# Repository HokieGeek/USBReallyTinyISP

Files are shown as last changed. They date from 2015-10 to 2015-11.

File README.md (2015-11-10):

# USBReallyTinyISP
SMT version of [Adafruit's USBtinyISP](https://learn.adafruit.com/usbtinyisp) with a form factor inspired by [SparkFun's AVR Adapter](http://www.sparkfun.com/products/retired/8508).

 This work is licensed as  *Creative Common 4.0 Attribution-ShareAlike*
## Schematic
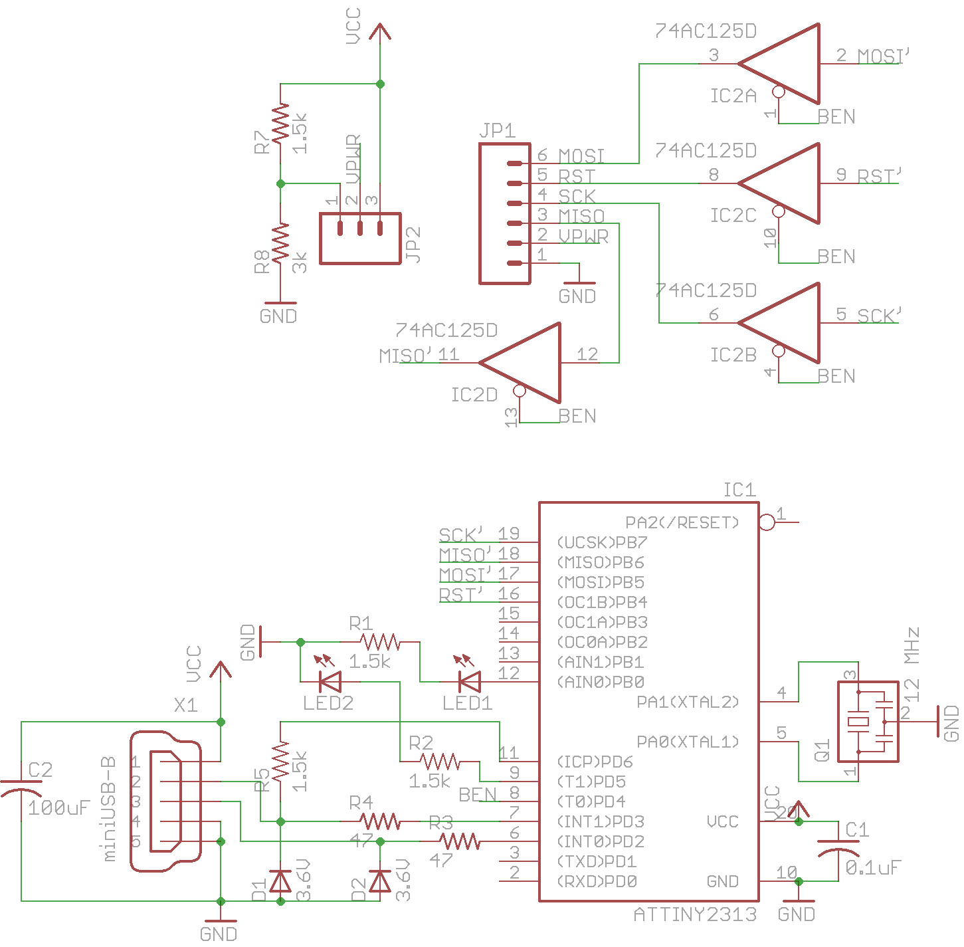
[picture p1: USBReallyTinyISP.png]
Latest USBReallyTinyISP Schematic


## Board
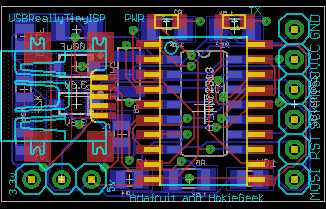
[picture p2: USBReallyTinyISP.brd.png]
Latest USBReallyTinyISP Board


## Datasheets
* [ATtiny2313](http://www.atmel.com/images/doc2543.pdf)
* [74AHC125](http://www.ti.com/lit/ds/symlink/sn74ahc125.pdf)

[Mouser project](https://www.mouser.com/ProjectManager/ProjectDetail.aspx?ProjectGUID=dc6b4dca-204f-45ba-9732-e10048a6dd5b)

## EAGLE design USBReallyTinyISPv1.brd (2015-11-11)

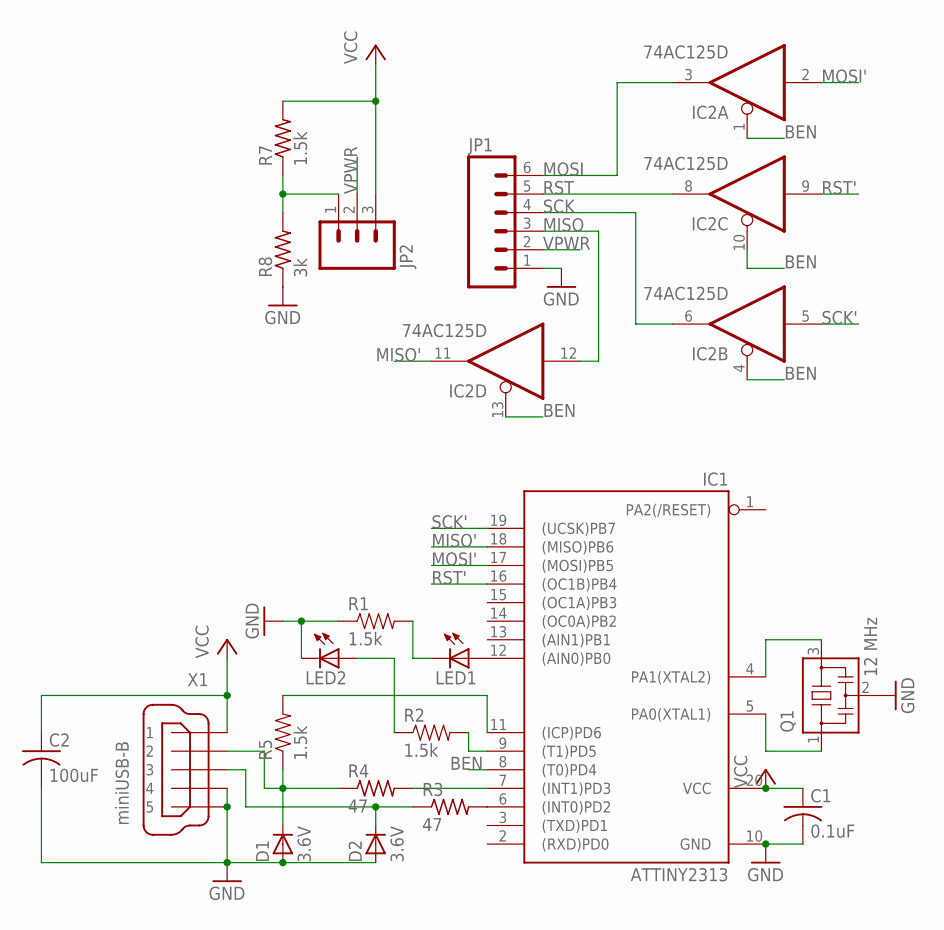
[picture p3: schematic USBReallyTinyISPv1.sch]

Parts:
C1: 0.1uF; C0805
C2: 100uF; C1206
D1, D2: 3.6V; SOD3718X135N
IC1: ATTINY2313; SO20L$
IC2: 74AC125D; SO14
JP1: M06SILK_FEMALE_PTH; 1X06
JP2: M03-SHORTEDPTH; 1X03
LED1, LED2: LEDSML0805; SML0805
Q1: 12 MHz; CSTCR6M
R1, R2, R5: 1.5k; 1206
R3, R4: 47; R0805
R7: 1.5k; R0805
R8: 3k; R0805
X1: miniUSB-B; UX60A-MB-5ST

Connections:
BEN: IC1.8 ((T0)PD4), IC2.1 (OE), IC2.4 (OE), IC2.10 (OE), IC2.13 (OE)
GND: C1.2, C2.2, D1.A, D2.A, IC1.10 (GND), IC2.7 (GND), JP1.1, LED2.C, Q1.2, R1.1, R8.1, X1.4, X1.5
MISO: IC2.12 (I), JP1.3
MISO': IC1.18 ((MISO)PB6), IC2.11 (O)
MOSI: IC2.3 (O), JP1.6
MOSI': IC1.17 ((MOSI)PB5), IC2.2 (I)
unnamed: IC1.12 ((AIN0)PB0), LED1.A
unnamed: IC1.4 (PA1(XTAL2)), Q1.3
unnamed: IC1.5 (PA0(XTAL1)), Q1.1
unnamed: IC1.9 ((T1)PD5), R2.2
unnamed: LED2.A, R2.1
unnamed: LED1.C, R1.2
unnamed: IC1.6 ((INT0)PD2), R3.2
unnamed: IC1.7 ((INT1)PD3), R4.2
unnamed: D2.K, R3.1, X1.3
unnamed: D1.K, R4.1, R5.1, X1.2
unnamed: IC1.11 ((ICP)PD6), R5.2
unnamed: JP2.1, R7.1, R8.2
RST: IC2.8 (O), JP1.5
RST': IC1.16 ((OC1B)PB4), IC2.9 (I)
SCK: IC2.6 (O), JP1.4
SCK': IC1.19 ((UCSK)PB7), IC2.5 (I)
VCC: C1.1, C2.1, IC1.20 (VCC), IC2.14 (VCC), JP2.3, R7.2, X1.1
VPWR: JP1.2, JP2.2

Board: 2 copper layers, 19 parts (13 on the bottom side), 24 nets, no tracks yet.

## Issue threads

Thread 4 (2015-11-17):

Burning the firmware

HokieGeek, 2015-11-17:
https://learn.adafruit.com/usbtinyisp/download

http://www.instructables.com/id/How-to-program-a-AVR-arduino-with-another-arduin/step5/Burning-USBtinyISP-firmware-to-an-attiny2313/

I need a 12Mhz Oscillator

HokieGeek, 2015-11-17:
This might also be useful: https://www.evernote.com/shard/s1/sh/29ff1183-5f8c-4804-89ac-341a6d078eab/1519438d16555fdd173236cf100c36a6

HokieGeek, 2015-11-17:
# Burning the firmware
1. Unpack the USBTinyISP firmware.
2. Go to the spi dir
3. Set the fuses:
```avrdude -P /dev/ttyUSB0 -c usbtiny -p t2313 -b 19200 -U hfuse:w:0xdf:m -U lfuse:w:0xef:m```
4. Attach the 12Mhz oscillator to *pins 4 and 5*
5. Burn the firmware:
```avrdude  -P /dev/ttyUSB0 -c usbtiny -p t2313 -b 19200 -B 1 -U flash:w:main.hex ```

HokieGeek, 2015-11-18:
### Reading from the chip
```avrdude -P /dev/ttyUSB0 -c usbtiny -p t2313 -U flash:r:flash.bin:r```

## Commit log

2015-10-13 Getting it ready for printing
    [USBReallyTinyISPv1.brd, USBReallyTinyISPv1.sch]
2015-10-13 Adding a pic of the schematic
2015-10-14 Really rethought the board arrangement and rerouted
    [USBReallyTinyISPv1.brd, USBReallyTinyISPv1.sch]
2015-10-14 Added schematic to the readme
2015-10-14 Added board image
2015-10-27 Got my boards back from OSH Park and really need bigger text!
    [USBReallyTinyISPv1.brd]
2015-10-27 Totally got the year wrong on the board.
    [USBReallyTinyISPv1.brd]
2015-10-27 Because it was just too big
    [USBReallyTinyISPv1.brd]
2015-10-28 Lots of tweaks to get a tiny little board!
    [USBReallyTinyISPv1.brd, USBReallyTinyISPv1.sch]
2015-10-28 Tweak Tweak!
    [USBReallyTinyISPv1.brd]
2015-10-30 Changed size of 1.5kOhm resistors
    [USBReallyTinyISPv1.brd, USBReallyTinyISPv1.sch]
2015-10-30 Updated headers to have bigger pads
    [USBReallyTinyISPv1.sch]
2015-10-31 Rerouted based on some updates
    [USBReallyTinyISPv1.brd]
2015-11-02 Working on the schematic as I start to find flaws in my design
    [USBReallyTinyISPv1.brd, USBReallyTinyISPv1.sch]
2015-11-11 Finally removed that freaking border
    [USBReallyTinyISPv1.brd, USBReallyTinyISPv1.sch]

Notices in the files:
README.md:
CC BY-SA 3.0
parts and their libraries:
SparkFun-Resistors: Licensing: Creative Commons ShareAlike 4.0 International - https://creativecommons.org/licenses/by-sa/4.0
